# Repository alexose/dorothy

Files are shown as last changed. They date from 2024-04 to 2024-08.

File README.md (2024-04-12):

# Dorothy - A Minimalist LoRa Sensor Platform

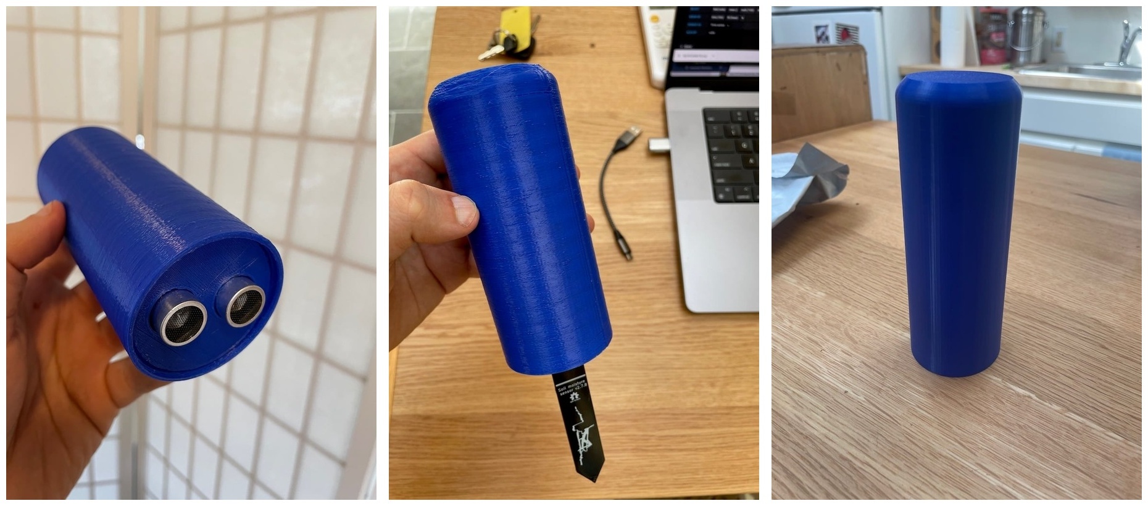
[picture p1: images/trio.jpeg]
Images of the Dorothy Sensor Platform


Dorothy is a minimalist, open-source, low-cost sensor platform built around the LoRa protocol. It uses the
[CubeCell V2](https://heltec.org/project/htcc-ab01-v2/) board and common off-the-shelf [sensors](#sensor) to deliver
readings to a central [hub](#hub), and only needs to be recharged about once per year.

Data is stored using [InfluxDB](https://www.influxdata.com/) and visualized with [Grafana](https://grafana.com/). This
software can be [run in the cloud](https://www.influxdata.com/influxcloud-trial/) or on a local Linux server.

Dorothy is aimed at anyone who wants to build a robust sensor network as cheaply as possible without being locked into a
proprietary platform.

## Key Features

-   **3D Printable**: All components are fully 3D printable with no supports.
-   **Weatherproof**: Designed to live outside year round.
-   **Long Range**: Capable of a range of at least 1/4 mile (400m).
-   **Long Battery Life**: Designed for a battery life of one year.
-   **Reliable**: Gracefully handles power and network outages.
-   **Easy to Assemble/Disassemble**: From the moment you're done printing, it takes about 20 minutes to assemble a
    working Dorothy, requiring minimal tools and skill. Just mount the components, screw it together, and you're set.
-   **Low Cost**: Around $25 per unit, including batteries
-   **Small Bill of Materials**
-   **Easy-to-read Codebase**
-   **Open Licensing**

## How to build

Begin by sourcing the materials you'll need to build a [hub](#hub) and at least one [sensor](#sensor):

-   [Heltec WiFi LoRa 32 v3](https://heltec.org/project/wifi-kit-32-v3/) (For the hub)
-   [Heltec CubeCell AB01 v2](https://heltec.org/project/htcc-ab01-v2/) (For each sensor)
-   At least three [18650 cells](https://www.amazon.com/s?k=18650)
-   Some [solid core wire](https://www.amazon.com/s?k=solid+core+wire)
-   [M2 screws](https://www.amazon.com/s?k=m2+screws+phillips) of assorted lengths
-   [1.25mm 2 pin Male JST Connectors](https://www.amazon.com/s?k=1.25mm+2pin+male+jst)
-   (Optional) These [pluggable LED Wire Connectors](https://www.amazon.com/s?k=Pluggable+LED+Wire+Connectors) which
    make it easy to quickly swap batteries in the field

And (depending on what you want to measure) your choice of:

-   [DHT22 Temperature/Humidity Sensor](https://www.amazon.com/dht22/s?k=dht22)
-   [US-100 Ultrasonic Distance Sensor](https://www.amazon.com/s?k=us100+sensor&ref=nb_sb_noss)
-   [I2C Soil Moisture Sensor](https://www.tindie.com/products/miceuz/i2c-soil-moisture-sensor/)

<h2 name="hub">Dorothy Hub</h2>

The [hub](https://github.com/alexose/3D-Printing/tree/main/Dorothy/hub) is a bridge between the battery-powered sensors
and your WiFi network. A hub is required in order to use Dorothy.

The hub is very small, and should only take you around an hour to print and assemble. Please follow the
[build instructions](https://github.com/alexose/3D-Printing/tree/main/Dorothy/hub) to get started.

<h2 name="sensor">Dorothy Sensor</h2>

The Dorothy Sensor is a cylinder containing three battery cells, a CubeCell board, and some type of sensor. At the time
of writing, it supports any of the three sensors listed above, but can be easily modified to support any sensor that
works on an ESP32 device.

Dorothy is designed around the [Cylindrical Battery Holder](https://www.thingiverse.com/thing:6080710) project, allowing
for easy battery pack swaps.

Please follow the full [build instructions](https://github.com/alexose/3D-Printing/tree/main/Dorothy/sensor) to get
started building your first Dorothy Sensor.

## Protocol

Dorothy simply uses the
[InfluxDB Line Protocol](https://docs.influxdata.com/influxdb/v1.3/write_protocols/line_protocol_tutorial/) to
communicate. While there are more efficient ways of sending messages, this reduces complexity and allows for easy
debugging.

## Future Work

While Dorothy has undergone over two years of development and testing at this point, there are still several
improvements that may appear in a future revision.

First on the list is improving the way the CubeCell board secures to the "brain". I'd love to get rid of those M2
screws, but I wasn't satisfied with any of the solutions I attempted.

Second is supporting more types of sensors, especially PIR sensors and even things like MEMS microphones.

Finally, there's always room to improve the software. Improvement doesn't necessarily mean adding features, however, but
making it simplier and easier to build on top of.

## Contributing

As Dorothy is an open-source project, contributions are always welcome! Check out the [CONTRIBUTING.md](link to
contributing guide) to get started.

## License

Dorothy is licensed under [insert license here](link to license).

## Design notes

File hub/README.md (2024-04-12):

# Dorothy Hub

The purpose of the Dorothy Hub is to rebroadcast [Dorothy](https://www.thingiverse.com/thing:6170483)'s LoRa messages
directly to an [InfluxDB](https://docs.influxdata.com/) server.

It uses the [Heltec WiFi LoRa 32](https://heltec.org/project/wifi-lora-32/), placed inside of this cool
[minimalist case](https://www.thingiverse.com/thing:3783207).

## Setting up InfluxDB

Because it's not possible to run InfluxDB on our ESP32 board, you'll need to get it running elsewhere.

While it is possible to use [InfluxDB Cloud](https://www.influxdata.com/products/influxdb-cloud/), I prefer to run it
for free on a local server. InfluxDB is quite snappy and runs just fine on a Raspberry Pi 3.

Check out [this page](https://pimylifeup.com/raspberry-pi-influxdb/) For a full tutorial on how to install InfluxDB on a
Raspberry Pi, as well as Grafana, a companion visualization library which outputs pretty graphs.

When you have a working InfluxDB installation, note the IP address of the device it's running on. You'll be needing it
later.

## Materials

Begin by sourcing all of the necessary materials:

-   One [Heltec WiFi LoRa 32](https://heltec.org/project/wifi-lora-32-v3)
-   One
    [Mini battery pack with JST connector](https://www.amazon.com/EEMB-2000mAh-Battery-Rechargeable-Connector/dp/B08214DJLJ)
    (optional, but allows for battery backup if your power goes out)
-   Around 10g of PLA filament

## 3D Printing

Use your favorite 3D printing software to print the
[Heltec WiFi LoRa 32 (V2) minimalist case](https://www.thingiverse.com/thing:3783207) at the highest quality settings.
It should only take you about an hour.

## Flashing

Connect your Heltec WiFi LoRa 32 board to your computer using a USB cable. Using the
[Arduino IDE](https://www.arduino.cc/en/software/), open the
[dorothy_hub.ino](https://github.com/alexose/3D-Printing/blob/main/Dorothy/hub/code/dorothy_hub/dorothy_hub.ino) file in
this repo.

You'll need to edit a few lines in order to point it at your network's correct SSID and password. Then, a few lines
below, edit the IP address to match the device that's running InfluxDB.

Now that you've edited the file to match your network, click the "Upload" button to send it to your device. This should
take about 20 seconds. Once your device reboots, it should connect to your WiFi network and start listening for incoming
LoRa messages.

You may now disconnect the device from your computer, connect the optional battery pack, connect the antenna, and
assemble the case as described in the [case documentation](https://www.thingiverse.com/thing:3783207).

Congratulations, you're now ready to receive and record measurements via the Dorothy platform!

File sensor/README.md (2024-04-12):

# Dorothy Sensor

The Dorothy Sensor platform is a simple, 3d printable case that houses a
[Heltec Cubecell](https://heltec.org/project/htcc-ab01-v2/) board, three battery cells, and one of three different types
of sensors.

It is designed to live outdoors, and can tolerate any environment that PLA can handle. With the correct sealant, it
should be able to operate underwater.

For measuring high heat environemnts, consider either printing in ABS or mounting the sensing element on a long wire.

## Materials

Begin by sourcing all of the necessary materials:

-   One [Heltec Cubecell AB01 V2](https://heltec.org/project/htcc-ab01-v2/)
-   One of the following sensors:
    -   [DHT22 Temperature/Humidity Sensor](https://www.amazon.com/dht22/s?k=dht22)
    -   [US-100 Ultrasonic Distance Sensor](https://www.amazon.com/s?k=us100+sensor&ref=nb_sb_noss)
    -   [I2C Soil Moisture Sensor](https://www.tindie.com/products/miceuz/i2c-soil-moisture-sensor/)
-   Three [18650 Lithium Ion cells](https://www.amazon.com/CWUU-Rechargeable-Battery-Headlamp-Flashlight/dp/B0CLY51NFH)
-   [Solid core wire](https://www.amazon.com/TUOFENG-Hookup-Wires-6-Different-Colored/dp/B07TX6BX47)

## 3D Printing

Use your favorite 3D printing software to print the following parts:

-   The [outer shell](https://github.com/alexose/3D-Printing/blob/main/Dorothy/sensor/outer_shell.stl)
-   A "brain" that matches your sensor type, e.g.,
    [distance_brain.stl](https://github.com/alexose/3D-Printing/blob/main/Dorothy/sensor/distance_brain.stl)
-   The [Cylindrical Battery Pack](https://www.thingiverse.com/thing:6080710)
-   Some short [M2 screws](https://www.amazon.com/HanTof-Washers-Assortment-Machine-Stainless/dp/B082XRX17Z)

You'll see that the housing is threaded. This allows for quick and easy assembly/disassembly of the device with no
tools.

## Assembly

Begin by connecting your choice of sensor to the CubeCell board. Typically, I just solder directly to it, but you may
want to attach headers first.

(Fritzing diagrams coming soon...)

Next, attach the board and the sensor to the "brain" mount. Note that there are various form factors depending on the
sensor type, but they typically involve a couple of M2 screws and some press-fitting.

Build the battery pack according to the [directions](https://www.thingiverse.com/thing:6080710). You may want to use
JST-type connectors, however, I find it somewhat difficult to disconnect those tiny connectors when everything is
mounted. Depending on your application, you might prefer to use
[this style](https://www.amazon.com/Pluggable-Connectors-Universal-Terminals-Wire-Stripping/dp/B07PRZMYD4) of
quick-connects to allow for easy swapping of battery packs.

## Flashing

Connect your Heltec CubeCell board to your computer using a USB cable. Using the
[Arduino IDE](https://www.arduino.cc/en/software/), open the .ino file that matches the sensor type you're using. For
example, if you're using a distance sensor, open up
[Dorothy_Distance.ino](https://github.com/alexose/3D-Printing/blob/main/Dorothy/sensor/code/Dorothy_Distance/Dorothy_Distance.ino).

Click the "upload" button to send the code to your cubecell device. After it restarts, it should begin sending messages
to your hub. This may be a good time to verify that your sensor is working correctly by reading the serial output of the
device.

You may now disconnect the device from your computer, connect it to the battery pack, and screw everything together.

Congratulations, you're now ready to place your sensor in its desired location and observe the readings over time!

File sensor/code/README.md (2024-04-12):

Thie file contains example code for the various types of sensors.

It's a bit ugly right now, but I tired to keep it as simple and hackable as possible.

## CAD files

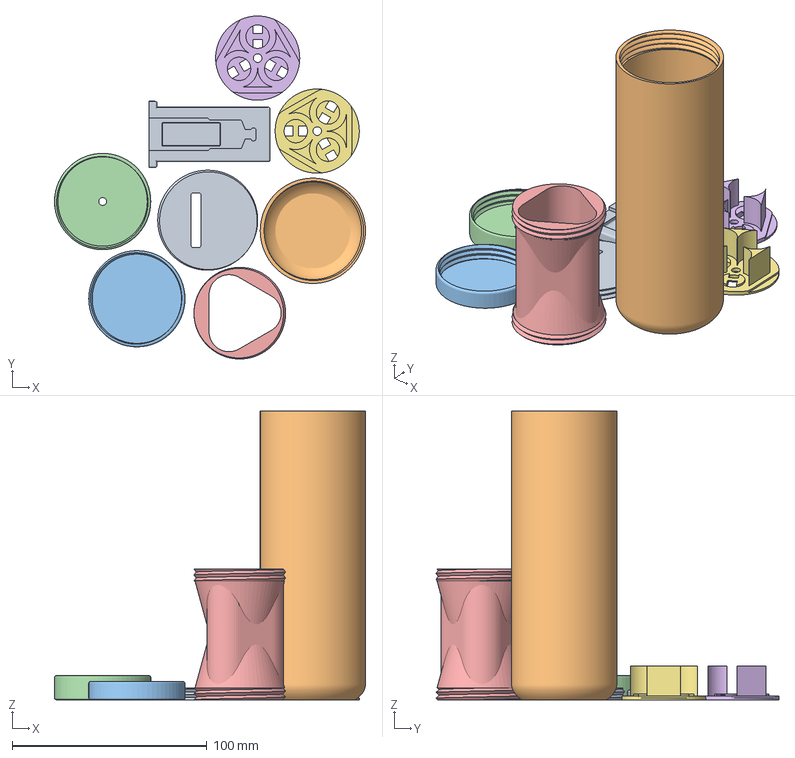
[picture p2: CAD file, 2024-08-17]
sensor/dorothy_soil_moisure.3mf
159.5 x 175.9 x 148.0 mm
soil_moisture_brain.stl
outer_shell.stl
cap.stl
cap_with_cutout.stl
tube.stl
plate.stl
plate.stl(1)

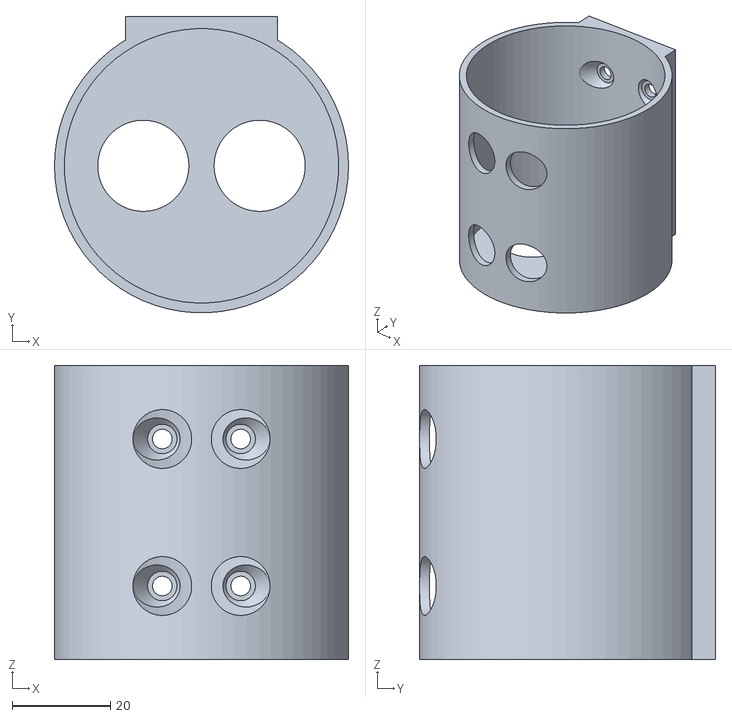
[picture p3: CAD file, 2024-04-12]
sensor/mount_1.stl
60.0 x 60.5 x 60.0

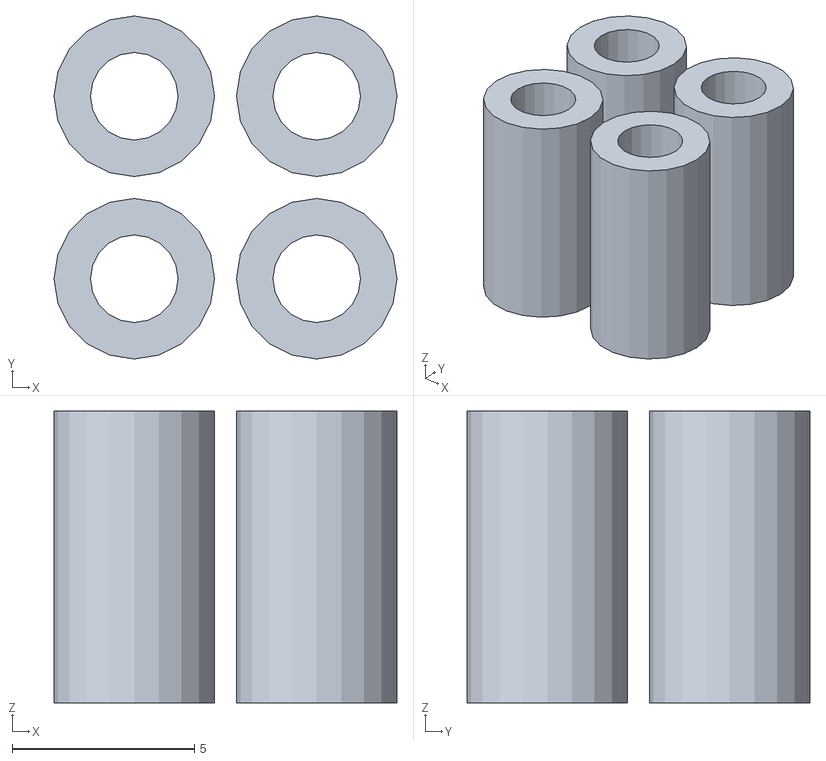
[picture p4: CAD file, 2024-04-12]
sensor/standoffs.stl
9.40 x 9.40 x 8.00

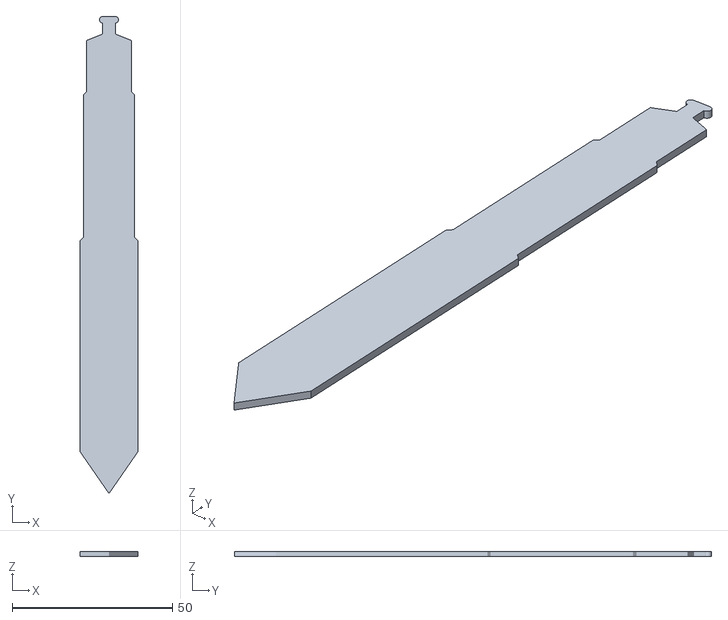
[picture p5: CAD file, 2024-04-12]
sensor/soil_moisture_sensor.stl
18.0 x 149.0 x 1.60

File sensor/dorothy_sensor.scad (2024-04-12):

/*

Dorothy Sensor
==============

(see also: Dorothy Hub)

The Dorothy Sensor Platform consists of three parts:

  1. Brain:  Where the sensors and CubeCell board are mounted.  Depending on the needs of the sensor,
    this usually is comprised of a "seal" (the threaded piece with the proper hole cut out) and a
    "sled" (the plate that the CubeCell board is attached to).
  2. Battery Pack:  Three 18650 cells placed in a Cylindrical Battery Holder (see: https://www.thingiverse.com/thing:6080710)
  3. Outer Shell: The threaded cylinder that covers the whole assembly and protects it from the elements

The Brain can come in many different shapes, depending on the type of sensor(s) you want to use.
This file includes variations for:

* US-100 ultrasonic sensor
* DHT22 temperature and humidity sensor
* Catnip Eletronics' soil moisture sensor (https://www.tindie.com/products/miceuz/i2c-soil-moisture-sensor/)

With more on the way!

*/


use <threads.scad>

// Parts
render_outer_shell = 1;
render_brain = 1;
render_standoffs = 1;
brain_type = "soil_moisture";  // distance, temperature_humidity, or soil_moisture


// Adjustable dimensions
thickness = 1;       // Thickness of wall.  Recommend 1mm to make room for threads
width = 27;          // Outer radius.  With 1mm thick walls, the inside radius becomes 25mm
dome_height = 8;     // Controls "Roundness" of shell
overhang = 4;        // Extra shell height to allow for a bit of overhang
tolerance = 0.3;     // Can be adjusted if threads don't fit together
fit_tolerance = 0.6; // Can be adjusted if inner shell doesn't fit
seal_padding = 0.5;  // Extra padding to allow annular seal to fit


// Non-adjustable dimensions
battery_pack_height = 75;
pitch = 2.8;
tooth_angle = 50;
seal_height = 6;
board_width = 28;
board_depth = 5;
thread_offset = 1.2;
sled_offset = 10;

// Note that while the board_height is 64mm, it goes through the 6mm "seal" and sticks about 3mm 
// into the battery pack.  So the total height of the brain ends up being 55mm.
board_height = 64;
    
// Height of inner "brain" compartment.  This needs to be a standard height so that shells are all
// compatible with one another.  
brain_height = 55; 


// The outer shell height should add up to the total height of all components smooshed together
height = battery_pack_height 
    + brain_height 
    + seal_height
    + overhang;

offset = width * 2.25;
if (render_brain) translate([0, 0, 0]) brain();
if (render_outer_shell) translate([offset, 0, 0]) outer_shell();
if (render_standoffs) translate([20, 0, 0]) cubecell_standoffs();

module brain() {
    if (brain_type == "distance") brain_distance();
    if (brain_type == "temperature_humidity") brain_temperature_humidity();
    if (brain_type == "soil_moisture") brain_soil_moisture();
}

module brain_distance() {
    // Distance module.  This is based on the US-100 ultrasonic sensor, available for about $2 on
    // ebay.  I prefer this sensor over other ultrasonic sensors because it has dedicated on-board 
    // timers, and outputs directly to serial.  
    //
    // The US-100 claims to work down to 2.4V, although it might be a good idea to add a 5V level converter.
    
    h = seal_height;
    w = width;
    
    sensor_width = 44 + fit_tolerance;
    sensor_height = 20 + fit_tolerance;
    sensor_depth = 3;

    sw = sensor_width;
    sh = sensor_height;
    sd = sensor_depth;
    
    bw = board_width;
    bh = board_height;

    difference() {
        union() {
            difference() {
                seal();
                translate([0, 0, h - (sd / 2) ]) {
                    translate([0, 0, 1]) {
                        cube([sw, sh, 3], center=true);
                        oval_cutout();
                    }
                }
                sensor_holes(h);
            }
        }
        
        union(){
            r = 1; // Mounting hole radius
            o = 4; // Mounting hole offset
            d = 5; // Mounting hole depth 
            translate([0, 0, h - d]) standoffs(r, d, sw - o, sh - o);              
        }
    }
    
    translate([sled_offset, 0]) sled_mount(sw, sh);
    
    module oval_cutout(){
        hull() translate([0, 0, -3.5]) standoffs(2, 2, 10, sensor_height-3);
    }
    
    module sensor_holes(h){
        hole_radius = 16/2 * 1.01;
        hole_distance = 23.75;
        f = 1.05;
        $fn = 150;
        
        translate([hole_distance/2, 0, 0]) cylinder(h*2, hole_radius*f, hole_radius*f);
        translate([-hole_distance/2, 0, 0]) cylinder(h*2, hole_radius*f, hole_radius*f);
    }
    
    translate([-45, 0, board_depth/2]) rotate([90, 180, 0]) sled(board_height - seal_height + 1);    
}
module brain_temperature_humidity() {
    // Temperature and humidity module.  This is based on the ubiquitous DHT22, which costs about $1.60.
    
    h = seal_height;
    w = width;
    
    sensor_width = 40 * 1.05; // fudged a bit
    sensor_height = 16 * 1.07;
    sensor_depth = 4;
    
    sw = sensor_width;
    sh = sensor_height;
    sd = sensor_depth;

    bw = board_width;
    bh = board_height;
    
    difference() {
        union() {
            
            difference() {
                seal();
                translate([0, 0, h - (sd / 2) ]) {
                    translate([0, 0, 1]) {
                        cube([sw, sh, 4.3], center=true);
                    }
                }
                translate([6, 0]) cube([20.3, 15.8, 20], center=true); 
            }
        }
    }
    
    translate([sled_offset, 0]) sled_mount(sw, sh);
    translate([-45, 0, board_depth/2]) rotate([90, 180, 0]) sled(board_height - seal_height + 1);
}

module brain_soil_moisture() {
    // Soil moisture module.  This hygrometer is based on the wonderful soil moisture sensor from
    // catnip electronics, and costs about $10:
    // https://www.tindie.com/products/miceuz/i2c-soil-moisture-sensor/
    //
    // The soil moisture sensor is mounted vertically, so the "spike" end sticks out of the bottom.
    h = seal_height;
    w = width;
    
    bw = board_width;
    bd = board_depth;
    bh = board_height;
    
    cutout_tolerance = 0.4;
    cutout = 8.5;
    t = 2.5;
    
    radius = 1;
    ww = 6;
    wd = 6;
    f = fit_tolerance;
    
    rotate([90, 0]) translate([-10, bd/2]) difference() {
        sled();
        union() {
        
            // Sensor cutout, with a little extra tolerance
            translate([0, 2.5, -50]) rotate([90, 0, 0]) scale([1, 1, 0.7])  minkowski() {
                import("soil_moisture_sensor.stl");
                cylinder(1, cutout_tolerance, cutout_tolerance);
            }
            
            // Extra cutout to give space for chips
            translate([0, 1, -8.5]) roundedcube([12, t+2.5, 30], true); 
        }
    }

    translate([-w*2, 0]) difference() {
        seal();
        offset = 6; // Gives a little extra breathing room for CubeCell
        voffset = 2; // Fudged this... room for improvement here
        translate([0, offset, bh/2 - voffset]) sled();
    }
}

module seal(){
    t = thickness;
    w = width - t*2;
    ScrewThread(w*2 + thread_offset, seal_height, pitch=pitch, tooth_angle=tooth_angle, tolerance=tolerance);
}

module sled(bh=board_height) {
    bw = board_width;
    bd = board_depth;
    
    h = seal_height;
    w = width;
    
    radius = 1;
    ww = 6;
    wd = 6;
    f = fit_tolerance;
    
    cx = 18.92;
    cy = 36.71;
    
    difference() {
        union() {
            roundedcube([bw, bd, bh], radius=radius, true);
            
            // Add "dogbones" which help lock the sled in place
            translate([bw/2, 0, -bh/2 + wd/2]) roundedcube([wd, bd, ww], radius=radius, true);
            translate([-bw/2, 0,  -bh/2 + wd/2]) roundedcube([wd, bd, ww], radius=radius, true);
            
            // Clips for CubeCell
            // translate([0, -4, 3]) rotate([90, 0, 0]) clips(cx - 7, cy);
        }
                    
        // Slice 2mm off bottom of roundedcube so that everything lines up nicely
        translate([0, 0, -bh+2]) cube([bw + wd * 2, bd, bh], true);
        
        // Mounting holes for CubeCell
        translate([0, 0, 3]) rotate([90, 0, 0]) standoffs(1, 10, cx, cy);
    }
}

module cubecell_standoffs() {
    h = 8;
    difference() {
        standoffs(1.2+thickness, h, 5, 5);
        standoffs(1.2, h, 5, 5);
    }
}
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

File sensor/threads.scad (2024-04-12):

// Created 2016-2017 by Ryan A. Colyer.
// This work is released with CC0 into the public domain.
// https://creativecommons.org/publicdomain/zero/1.0/
//
// https://www.thingiverse.com/thing:1686322
//
// v2.1


screw_resolution = 0.2;  // in mm


// Provides standard metric thread pitches.
function ThreadPitch(diameter) =
  (diameter <= 64) ?
    lookup(diameter, [
      [2, 0.4],
      [2.5, 0.45],
      [3, 0.5],
      [4, 0.7],
      [5, 0.8],
      [6, 1.0],
      [7, 1.0],
      [8, 1.25],
      [10, 1.5],
      [12, 1.75],
      [14, 2.0],
      [16, 2.0],
      [18, 2.5],
      [20, 2.5],
      [22, 2.5],
      [24, 3.0],
      [27, 3.0],
      [30, 3.5],
      [33, 3.5],
      [36, 4.0],
      [39, 4.0],
      [42, 4.5],
      [48, 5.0],
      [52, 5.0],
      [56, 5.5],
      [60, 5.5],
      [64, 6.0]
    ]) :
    diameter * 6.0 / 64;


// Provides standard metric hex head widths across the flats.
function HexAcrossFlats(diameter) =
  (diameter <= 64) ?
    lookup(diameter, [
      [2, 4],
      [2.5, 5],
      [3, 5.5],
      [3.5, 6],
      [4, 7],
      [5, 8],
      [6, 10],
      [7, 11],
      [8, 13],
      [10, 16],
      [12, 18],
      [14, 21],
      [16, 24],
      [18, 27],
      [20, 30],
      [22, 34],
      [24, 36],
      [27, 41],
      [30, 46],
      [33, 50],
      [36, 55],
      [39, 60],
      [42, 65],
      [48, 75],
      [52, 80],
      [56, 85],
      [60, 90],
      [64, 95]
    ]) :
    diameter * 95 / 64;

// Provides standard metric hex head widths across the corners.
function HexAcrossCorners(diameter) =
  HexAcrossFlats(diameter) / cos(30);


// Provides standard metric hex (Allen) drive widths across the flats.
function HexDriveAcrossFlats(diameter) =
  (diameter <= 64) ?
    lookup(diameter, [
      [2, 1.5],
      [2.5, 2],
      [3, 2.5],
      [3.5, 3],
      [4, 3],
      [5, 4],
      [6, 5],
      [7, 5],
      [8, 6],
      [10, 8],
      [12, 10],
      [14, 12],
      [16, 14],
      [18, 15],
      [20, 17],
      [22, 18],
      [24, 19],
      [27, 20],
      [30, 22],
      [33, 24],
      [36, 27],
      [39, 30],
      [42, 32],
      [48, 36],
      [52, 36],
      [56, 41],
      [60, 42],
      [64, 46]
    ]) :
    diameter * 46 / 64;

// Provides standard metric hex (Allen) drive widths across the corners.
function HexDriveAcrossCorners(diameter) =
  HexDriveAcrossFlats(diameter) / cos(30);

// Provides metric countersunk hex (Allen) drive widths across the flats.
function CountersunkDriveAcrossFlats(diameter) =
  (diameter <= 14) ?
    HexDriveAcrossFlats(HexDriveAcrossFlats(diameter)) :
    round(0.6*diameter);

// Provides metric countersunk hex (Allen) drive widths across the corners.
function CountersunkDriveAcrossCorners(diameter) =
  CountersunkDriveAcrossFlats(diameter) / cos(30);

// Provides standard metric nut thickness.
function NutThickness(diameter) =
  (diameter <= 64) ?
    lookup(diameter, [
      [2, 1.6],
      [2.5, 2],
      [3, 2.4],
      [3.5, 2.8],
      [4, 3.2],
      [5, 4.7],
      [6, 5.2],
      [7, 6.0],
      [8, 6.8],
      [10, 8.4],
      [12, 10.8],
      [14, 12.8],
      [16, 14.8],
      [18, 15.8],
      [20, 18.0],
      [22, 21.1],
      [24, 21.5],
      [27, 23.8],
      [30, 25.6],
      [33, 28.7],
      [36, 31.0],
      [42, 34],
      [48, 38],
      [56, 45],
      [64, 51]
    ]) :
    diameter * 51 / 64;


// This generates a closed polyhedron from an array of arrays of points,
// with each inner array tracing out one loop outlining the polyhedron.
// pointarrays should contain an array of N arrays each of size P outlining a
// closed manifold.  The points must obey the right-hand rule.  For example,
// looking down, the P points in the inner arrays are counter-clockwise in a
// loop, while the N point arrays increase in height.  Points in each inner
// array do not need to be equal height, but they usually should not meet or
// cross the line segments from the adjacent points in the other arrays.
// (N>=2, P>=3)
// Core triangles:
//   [j][i], [j+1][i], [j+1][(i+1)%P]
//   [j][i], [j+1][(i+1)%P], [j][(i+1)%P]
//   Then triangles are formed in a loop with the middle point of the first
//   and last array.
module ClosePoints(pointarrays) {
  function recurse_avg(arr, n=0, p=[0,0,0]) = (n>=len(arr)) ? p :
    recurse_avg(arr, n+1, p+(arr[n]-p)/(n+1));

  N = len(pointarrays);
  P = len(pointarrays[0]);
  NP = N*P;
  lastarr = pointarrays[N-1];
  midbot = recurse_avg(pointarrays[0]);
  midtop = recurse_avg(pointarrays[N-1]);

  faces_bot = [
    for (i=[0:P-1])
      [0,i+1,1+(i+1)%len(pointarrays[0])]
  ];

  loop_offset = 1;
  bot_len = loop_offset + P;

  faces_loop = [
    for (j=[0:N-2], i=[0:P-1], t=[0:1])
      [loop_offset, loop_offset, loop_offset] + (t==0 ?
      [j*P+i, (j+1)*P+i, (j+1)*P+(i+1)%P] :
      [j*P+i, (j+1)*P+(i+1)%P, j*P+(i+1)%P])
  ];

  top_offset = loop_offset + NP - P;
  midtop_offset = top_offset + P;

  faces_top = [
    for (i=[0:P-1])
      [midtop_offset,top_offset+(i+1)%P,top_offset+i]
  ];

  points = [
    for (i=[-1:NP])
      (i<0) ? midbot :
      ((i==NP) ? midtop :
      pointarrays[floor(i/P)][i%P])
  ];
  faces = concat(faces_bot, faces_loop, faces_top);

  polyhedron(points=points, faces=faces);
}



// This creates a vertical rod at the origin with external threads.  It uses
// metric standards by default.
module ScrewThread(outer_diam, height, pitch=0, tooth_angle=30, tolerance=0.4, tip_height=0, tooth_height=0, tip_min_fract=0) {

  pitch = (pitch==0) ? ThreadPitch(outer_diam) : pitch;
  tooth_height = (tooth_height==0) ? pitch : tooth_height;
  tip_min_fract = (tip_min_fract<0) ? 0 :
    ((tip_min_fract>0.9999) ? 0.9999 : tip_min_fract);

  outer_diam_cor = outer_diam + 0.25*tolerance; // Plastic shrinkage correction
  inner_diam = outer_diam - tooth_height/tan(tooth_angle);
  or = (outer_diam_cor < screw_resolution) ?
    screw_resolution/2 : outer_diam_cor / 2;
  ir = (inner_diam < screw_resolution) ? screw_resolution/2 : inner_diam / 2;
  height = (height < screw_resolution) ? screw_resolution : height;

  steps_per_loop_try = ceil(2*3.14159265359*or / screw_resolution);
  steps_per_loop = (steps_per_loop_try < 4) ? 4 : steps_per_loop_try;
  hs_ext = 3;
  hsteps = ceil(3 * height / pitch) + 2*hs_ext;

  extent = or - ir;

  tip_start = height-tip_height;
  tip_height_sc = tip_height / (1-tip_min_fract);

  tip_height_ir = (tip_height_sc > tooth_height/2) ?
    tip_height_sc - tooth_height/2 : tip_height_sc;

  tip_height_w = (tip_height_sc > tooth_height) ? tooth_height : tip_height_sc;
  tip_wstart = height + tip_height_sc - tip_height - tip_height_w;


  function tooth_width(a, h, pitch, tooth_height, extent) =
    let(
      ang_full = h*360.0/pitch-a,
      ang_pn = atan2(sin(ang_full), cos(ang_full)),
      ang = ang_pn < 0 ? ang_pn+360 : ang_pn,
      frac = ang/360,
      tfrac_half = tooth_height / (2*pitch),
      tfrac_cut = 2*tfrac_half
    )
    (frac > tfrac_cut) ? 0 : (
      (frac <= tfrac_half) ?
        ((frac / tfrac_half) * extent) :
        ((1 - (frac - tfrac_half)/tfrac_half) * extent)
    );


  pointarrays = [
    for (hs=[0:hsteps])
      [
        for (s=[0:steps_per_loop-1])
          let(
            ang_full = s*360.0/steps_per_loop,
            ang_pn = atan2(sin(ang_full), cos(ang_full)),
            ang = ang_pn < 0 ? ang_pn+360 : ang_pn,

            h_fudge = pitch*0.001,

            h_mod =
              (hs%3 == 2) ?
                ((s == steps_per_loop-1) ? tooth_height - h_fudge : (
                 (s == steps_per_loop-2) ? tooth_height/2 : 0)) : (
              (hs%3 == 0) ?
                ((s == steps_per_loop-1) ? pitch-tooth_height/2 : (
                 (s == steps_per_loop-2) ? pitch-tooth_height + h_fudge : 0)) :
                ((s == steps_per_loop-1) ? pitch-tooth_height/2 + h_fudge : (
                 (s == steps_per_loop-2) ? tooth_height/2 : 0))
              ),

            h_level =
              (hs%3 == 2) ? tooth_height - h_fudge : (
              (hs%3 == 0) ? 0 : tooth_height/2),

            h_ub = floor((hs-hs_ext)/3) * pitch
              + h_level + ang*pitch/360.0 - h_mod,
            h_max = height - (hsteps-hs) * h_fudge,
            h_min = hs * h_fudge,
            h = (h_ub < h_min) ? h_min : ((h_ub > h_max) ? h_max : h_ub),

            ht = h - tip_start,
            hf_ir = ht/tip_height_ir,
            ht_w = h - tip_wstart,
            hf_w_t = ht_w/tip_height_w,
            hf_w = (hf_w_t < 0) ? 0 : ((hf_w_t > 1) ? 1 : hf_w_t),
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

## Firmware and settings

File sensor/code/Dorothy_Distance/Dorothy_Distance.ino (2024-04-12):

#include "LoRaWan_APP.h"
#include "Arduino.h"
#include "softSerial.h"
#include <Wire.h>

#define timetowake 1000 * 60 * 5 // five minutes

String host_id = "distance_1"; // Change this to whatever you want!
String distance;
String voltage = "0";

#define timetosleep 300 // 300 milliseconds

static TimerEvent_t sleep;
static TimerEvent_t wakeup;
uint8_t lowpower = 1;
bool done = false;

#define RF_FREQUENCY                                868000000
#define TX_OUTPUT_POWER                             14
#define LORA_BANDWIDTH                              0
#define LORA_SPREADING_FACTOR                       8
#define LORA_CODINGRATE                             4
#define LORA_PREAMBLE_LENGTH                        8
#define LORA_SYMBOL_TIMEOUT                         0
#define LORA_FIX_LENGTH_PAYLOAD_ON                  false
#define LORA_IQ_INVERSION_ON                        false
#define RX_TIMEOUT_VALUE                            1000
#define BUFFER_SIZE                                 30

char txPacket[BUFFER_SIZE];

static RadioEvents_t RadioEvents;
void OnTxDone( void );
void OnTxTimeout( void );

softSerial softwareSerial(GPIO1 /*TX pin*/, GPIO2 /*RX pin*/);

typedef enum
{
  LOWPOWER,
  ReadVoltage,
  TX
} States_t;

States_t state;
bool sleepMode = false;
int16_t rssi, rxSize;

void setup() {

  Wire.begin();
  Serial.begin(115200);
  Serial.println( "[stup] INIT");

  sensor.begin(); // reset sensor
  delay(1000);

  rssi = 0;

  RadioEvents.TxDone = OnTxDone;
  RadioEvents.TxTimeout = OnTxTimeout;

  Radio.Init( &RadioEvents );
  Radio.SetChannel( RF_FREQUENCY );
  Radio.SetTxConfig( MODEM_LORA, TX_OUTPUT_POWER, 0, LORA_BANDWIDTH,
    LORA_SPREADING_FACTOR, LORA_CODINGRATE,
    LORA_PREAMBLE_LENGTH, LORA_FIX_LENGTH_PAYLOAD_ON,
    true, 0, 0, LORA_IQ_INVERSION_ON, 3000 );

  TimerInit( &sleep, OnSleep );
  TimerInit( &wakeup, OnWakeup );
  OnSleep();
}


uint32_t out_flag_1 = 0;
uint32_t out_flag_2 = 0;
uint32_t t1;
uint32_t t2;

void time1()
{
  out_flag_1 = 1;
  t1 = micros();
}

void time2()
{
  out_flag_2 = 1;
  t2 = micros();
}

void loop()
{
  if (lowpower)
  {
    //note that LowPower_Handler() run six times the mcu into lowpower mode;
    lowPowerHandler();
  } else if (!done) {

    // Turn on device
    pinMode(Vext, OUTPUT);
    digitalWrite(Vext, LOW);
    delay(500);

    pinMode(GPIO1, OUTPUT);
    pinMode(GPIO2, INPUT);    
    //software serial init

    softwareSerial.begin(9600);
    softwareSerial.flush();

    delay(200);
    distance = readDistance();
    distance = readDistance();
    int temperature = readTemp();
    
    Serial.println(distance);
    Serial.println(temperature);

    float temperature_f = 1.8 * temperature + 32;
    String temperature_formatted = String(temperature_f, 1);

     // Read voltage
    pinMode(VBAT_ADC_CTL, OUTPUT);
    digitalWrite(VBAT_ADC_CTL, LOW);
    float c = getBatteryVoltage();
    voltage = String(c / 1000, 4);
    pinMode(VBAT_ADC_CTL, INPUT);
    delay(100);
  
    // Send reading
    Radio.IrqProcess();

    // InfluxDB line protocol format
    String blah = "dorothy,host=" + host_id + 
    " temperature=" + temperature_formatted + 
    ",distance=" + distance +
    ",voltage=" + voltage;

    Serial.print(blah);
    Radio.Send((uint8_t *)blah.c_str(), blah.length() );
  
    delay(100);
    
    detachInterrupt(GPIO2); // prevents system hang after switching power off
     
    Wire.end();
    pinMode(Vext, OUTPUT);  
    digitalWrite(Vext, HIGH);
    delay(500);

    done = true;
    TimerSetValue( &sleep, timetosleep );
    TimerStart( &sleep );
  }
}

int readDistance()
{
  unsigned int highByte = 0;
  unsigned int lowByte = 0;
  unsigned int dist = 0;

  softwareSerial.flush();
  softwareSerial.sendByte(0X55);
  delay(500);
  if (softwareSerial.available() >= 2)
  {

    highByte = softwareSerial.read();
    lowByte = softwareSerial.read();
    dist = highByte * 256 + lowByte;          // Calculate the distance
    if ((dist > 1) && (dist < 10000))
    {
      return dist;
    }
  }
}

int readTemp()
{
  unsigned int temp = 0;
  softwareSerial.sendByte(0X50);
  delay(100);
  if (softwareSerial.available() >= 1)
  {
      temp = softwareSerial.read() - 45; // celcius
      softwareSerial.flush();
      return temp;
  }
}

void OnSleep()
{
  Serial.printf("[lowp] lowpower mode  %d ms\r\n", timetowake);
  lowpower = 1;
  
  //timetosleep ms later wake up;
  Radio.Sleep();
  TimerSetValue( &wakeup, timetowake );
  TimerStart( &wakeup );
}

void OnWakeup()
{
  Serial.printf("[wkup] wake up, %d ms later into lowpower mode.\r\n", timetosleep);
  uint32_t currentTime = TimerGetCurrentTime() / 1000;
  Serial.printf("[time] upTime: %d sec. \r\n", currentTime);

  done = false;
  lowpower = 0;
}

void OnTxDone( void )
{
  Serial.print("TX done!");
}

void OnTxTimeout( void )
{
  Serial.print("TX Timeout......");
}

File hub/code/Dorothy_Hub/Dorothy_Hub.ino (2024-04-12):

#include <SPI.h>
#include <WiFi.h>
#include <WiFiUDP.h>
#include "DHTesp.h"
#include "heltec.h"
#include <Wire.h>

#define BAND 868E6

String rssi = "RSSI --";
String packSize = "--";
String packet ;

char ssid[] = "YOUR_SSID";     //  your network SSID (name) 
char pass[] = "YOUR_PASSWORD";    // your network password
int status = WL_IDLE_STATUS;     // the Wifi radio's status

// the IP address of your InfluxDB host
byte host[] = {192, 168, 1, 46};

// the port that the InfluxDB UDP plugin is listening on
int port = 8089;

WiFiUDP udp;

void setup() {

  Heltec.begin(true /*DisplayEnable Enable*/, true /*Heltec.Heltec.Heltec.LoRa Disable*/, true /*Serial Enable*/, true /*PABOOST Enable*/, BAND /*long BAND*/);
  Heltec.display->init();
  Heltec.display->setFont(ArialMT_Plain_10);

  LoRa.setSpreadingFactor(8);
    // put in standby mode
  LoRa.setSignalBandwidth(125E3);
  LoRa.setCodingRate4(4);
  LoRa.setSyncWord(0x12);   //0x34
  LoRa.setPreambleLength(8);

  delay(2000);

  adcAttachPin(37);
  analogSetClockDiv(255); // 1338mS

  Heltec.display->drawString(0, 0, "Connecting to ");
  Heltec.display->drawString(0, 10, ssid);
  Heltec.display->display();
  
  // initialize serial port
  Serial.begin(115200);

  // attempt to connect using WPA2 encryption
  Serial.println("Attempting to connect to WPA network...");
  WiFi.disconnect();
  delay(10);
  status = WiFi.begin(ssid, pass);
  
  while (WiFi.status() != WL_CONNECTED) {
      delay(500);
      Heltec.display->drawString(0, 20, ".");
      Heltec.display->display();
      Serial.println(WiFi.status());

  }
  
  // if the connection succeeded, print network info
  Serial.println("Connected to network");
  // print your WiFi shield's IP address:
  IPAddress ip = WiFi.localIP();
  
  Serial.print("IP Address: ");
  Serial.println(ip);

  Heltec.display->drawString(0, 30, "Connected! IP: ");
  Heltec.display->drawString(0, 40, ip.toString().c_str());
  Heltec.display->display();
  
  // print the received signal strength:
  long rssi = WiFi.RSSI();
  Serial.print("WiFi signal strength (RSSI):");
  Serial.print(rssi);
  Serial.println(" dBm");
  digitalWrite(21,LOW);

  LoRa.receive();
}

void LoRaData(){
  String line;
  
  char str_array[packet.length() + 1];
  packet.toCharArray(str_array, packet.length());
  
  Heltec.display->clear();
  Heltec.display->setTextAlignment(TEXT_ALIGN_LEFT);
  Heltec.display->setFont(ArialMT_Plain_10);
  Heltec.display->drawStringMaxWidth(0 , 0 , 128, packet);
  Heltec.display->display();

  // send the packet
  Serial.println("Sending UDP packet...");
  Serial.println(packet);

  udp.beginPacket(host, port);
  udp.print(packet);
  udp.endPacket();

  digitalWrite(25,LOW);
  Serial.println("Done!");
}

void cbk(int packetSize) {
  packet ="";
  packSize = String(packetSize,DEC);
  for (int i = 0; i < packetSize; i++) { packet += (char) LoRa.read(); }
  rssi = "RSSI " + String(LoRa.packetRssi(), DEC) ;
  LoRaData();
}

void loop() {
  int packetSize = LoRa.parsePacket();
  if (packetSize) { cbk(packetSize);  }
  delay(50);

  if (WiFi.status() != WL_CONNECTED){
    Heltec.display->drawString(0, 0, "Wifi disconnected...");
    Heltec.display->display();
    delay(2000);
    setup();
    return;
  }
}

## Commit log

2024-08-17 Add Cura project
    [cap_with_sled_cutout.stl, dorothy_soil_moisure.3mf]
2024-08-20 Incredibly silly idea with annular press-fit
    Revert "Incredibly silly idea with annular press-fit"
    This reverts commit 25474d41c42cff9a703f4f35a617fd1e6ffe0d60.
    Revert "Revert "Incredibly silly idea with annular press-fit""
    This reverts commit 76af809b16eb018192e635007043dfd68772e52e.
    Work on caddy
    [dorothy_sensor.scad]
2024-08-20 Revert "Incredibly silly idea with annular press-fit"
    This reverts commit f0550ca55f09b85a1d0889716e36f93b3532ab66.
    [dorothy_sensor.scad]
